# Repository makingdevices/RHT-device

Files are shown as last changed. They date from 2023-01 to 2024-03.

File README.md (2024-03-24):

<!-- Improved compatibility of back to top link: See: https://github.com/othneildrew/Best-README-Template/pull/73 -->

<!--
*** Thanks for checking out the Best-README-Template. If you have a suggestion
*** that would make this better, please fork the repo and create a pull request
*** or simply open an issue with the tag "enhancement".
*** Don't forget to give the project a star!
*** Thanks again! Now go create something AMAZING! :D
-->

<!-- PROJECT SHIELDS -->
<!--
*** I'm using markdown "reference style" links for readability.
*** Reference links are enclosed in brackets [ ] instead of parentheses ( ).
*** See the bottom of this document for the declaration of the reference variables
*** for contributors-url, forks-url, etc. This is an optional, concise syntax you may use.
*** https://www.markdownguide.org/basic-syntax/#reference-style-links
-->
[][ig-url]
[][sponsor-url]
[][stars-url]
[][issues-url]
[][linkedin-url]

<!-- PROJECT LOGO -->
<br />
<div align="center">
  <a href="https://makingdevices.com/links/">
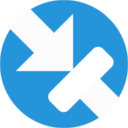
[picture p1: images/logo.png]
    
  </a>

<h3 align="center">Making Devices</h3>

  <p align="center">
    Open Source projects where we struggle with engineering, electronics, coding and who knows what else... In this case, RHT Device is a very simple humidity and temperature sensor, so hopefully you may find it interesting ;)
  </p>
</div>

<!-- TABLE OF CONTENTS -->
<details>
  <summary>Table of Contents</summary>
  <ol>
    <li>
      <a href="#about-the-project">About The Project</a>
      <ul>
        <li><a href="#built-with">Built With</a></li>
      </ul>
    </li>
    <li>
      <a href="#Build-one">Build one</a>
      <ul>
      </ul>
    </li>
    <li><a href="#usage">Usage</a></li>
    <li><a href="#roadmap">Roadmap</a></li>
    <li><a href="#license">License</a></li>
    <li><a href="#contact">Contact</a></li>
    <li><a href="#Sponsor">Sponsor</a></li>
  </ol>
</details>

<!-- ABOUT THE PROJECT -->
## About The Project

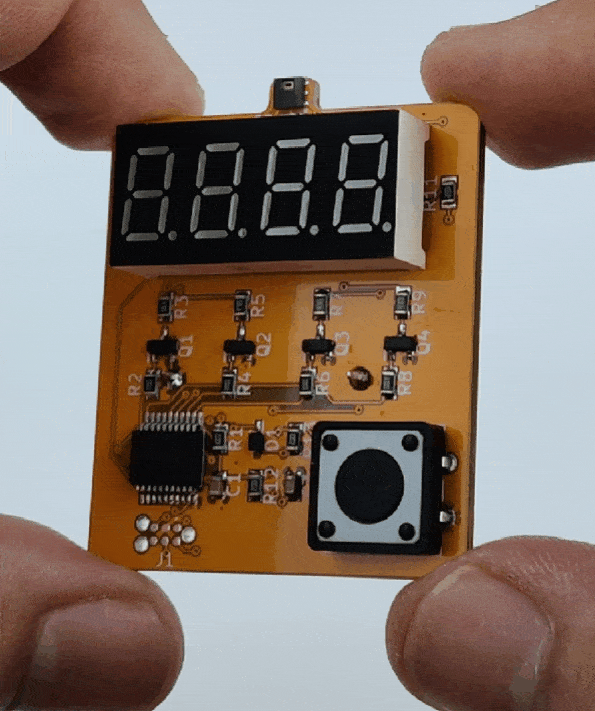
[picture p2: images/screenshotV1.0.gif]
Bytes Counter Shot
[](https://github.com/makingdevices/RHT-device)

RHT Device is a very simple relative humidity and temperature sensor that shows the data in the screen. The project was chosen to test the I2C communication of the PIC18F14k50. 

<p align="right">(<a href="#readme-top">back to top</a>)</p>

### Built With

[][PIC-url]
[][MPLAB-C-url]
[][kicad-url]
[][sponsor-url]

<p align="right">(<a href="#readme-top">back to top</a>)</p>

<!-- GETTING STARTED -->

## Build one
Documentation is being updated.

1. Get the gerber files for the latest version: [V1.0](https://github.com/makingdevices/RHT-device/tree/main/Gerber/Gerber_v1.0.zip) 
2. Send them to a PCB manufacturer ([Our Sponsor is PCBWAY][sponsor-url])
3. You should solder all the components in the board. ([The schematic is available here v1.0][schematic-url])
4. Program the firmware into the pic. ([V1.0 is here][firmware-url])

Enjoy :)

<p align="right">(<a href="#readme-top">back to top</a>)</p>

<!-- USAGE EXAMPLES -->
## Usage

Instructions of use:

- When the button is pressed, the temperature is shown.
- Next time the button is pressed, relative humidity is shown. It will change between temperature and humidity
- After 10s of no use, the screen will be off and the device enters sleep mode.
- One button click will wake up the device for another 10s

<p align="right">(<a href="#readme-top">back to top</a>)</p>

<!-- ROADMAP -->
## Roadmap

- [x] Finish the firmware for the PIC18F14K50
- [x] Validate the RHT-Device board V1.0
- [x] Update all the documentation

See the [open issues](https://github.com/makingdevices/RHT-device/issues) for a full list of proposed features (and known issues).

State: Project <b>FINISHED</b> - 11/05/2023

<p align="right">(<a href="#readme-top">back to top</a>)</p>

<!-- Power Consumption -->
## Power Consumption

One of the main requisites for the board is to obtain a minimum power consumption so the device can live from a coin cell. When the screen is on we obtain:

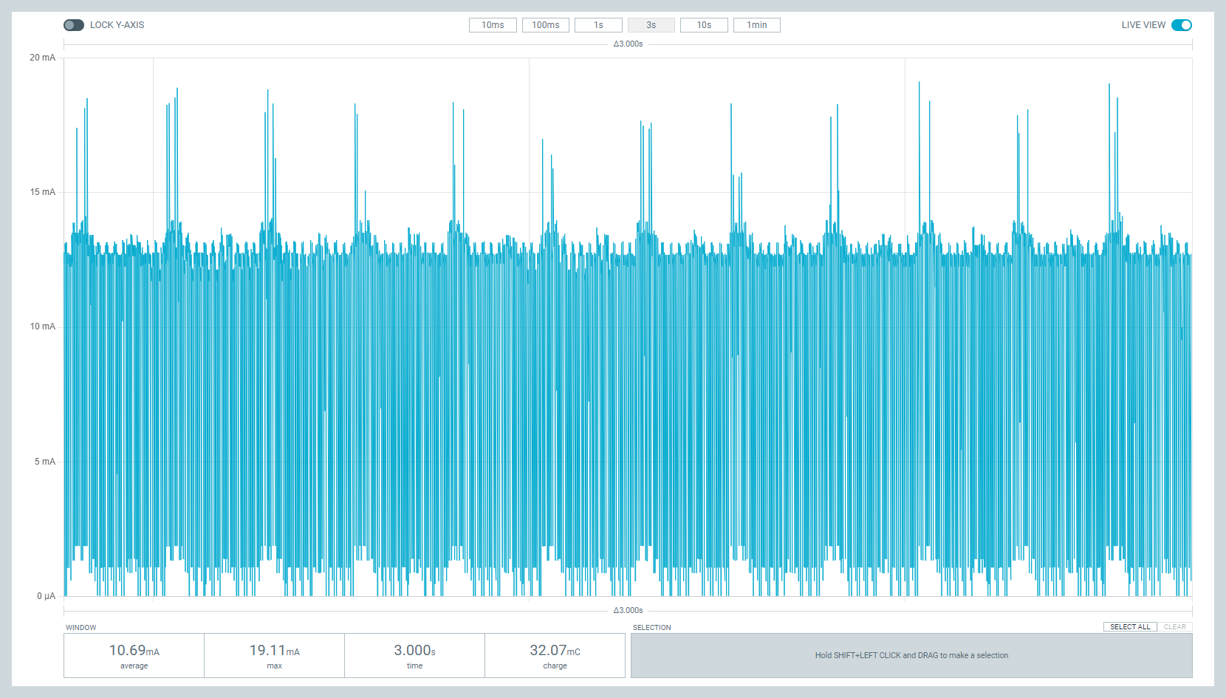
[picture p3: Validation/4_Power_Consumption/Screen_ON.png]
ON Screen consumption Shot
[](https://github.com/makingdevices/RHT-device/tree/main/Validation/)

<b>Average Current</b> = 10.69mA

In sleep mode, the power consumption is as follows:

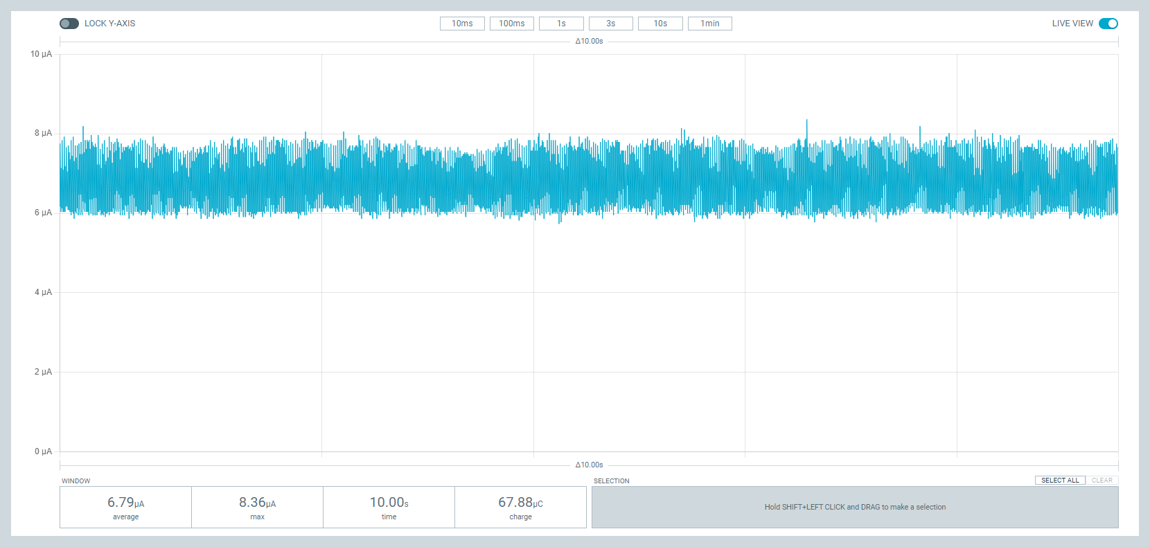
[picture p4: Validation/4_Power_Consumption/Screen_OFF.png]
OFF Screen consumption Shot
[](https://github.com/makingdevices/RHT-device/tree/main/Validation/)

<b>Average Current</b> = 6.79uA

With this data and a normal use of 5 reading a day, the battery should last for several years.

<p align="right">(<a href="#readme-top">back to top</a>)</p>

<!-- LICENSE -->
## License

Distributed under three licenses:
- [Hardware](/License/HW_cern_ohl_s_v2.pdf)
- [Software](/License/SW_GPLv3.0.txt)
- [Documentation](/License/Documentation_CC-BY-SA-4.0.txt)

[GPL v3 License][license-url] 
<p align="right">(<a href="#readme-top">back to top</a>)</p>

<!-- CONTACT -->
## Contact

Making Devices - [@MakingDevices](https://www.instagram.com/makingdevices/)

Project Link: [https://github.com/makingdevices/Thermo-device-logger](https://github.com/makingdevices/RHT-device/)

Other Links: [LinkTree](https://makingdevices.com/links/)

<p align="right">(<a href="#readme-top">back to top</a>)</p>

<!-- Sponsor -->
## Sponsor

[PCBWAY](https://www.pcbway.com/?from=makingdevices) is the most professional PCB manufacturer for prototyping and low-volume production to work with in the world. With more than a decade in the field, They are committed to meeting the needs of their customers from different industries in terms of quality, delivery, cost-effectiveness and any other demanding requests. As Sponsor of Making Devices, they will be in charge of all the PCBs for MDV, allowing both of us to grow together in a long term partnership. We hope you take them into account for your both personal and professional prototypes or products.

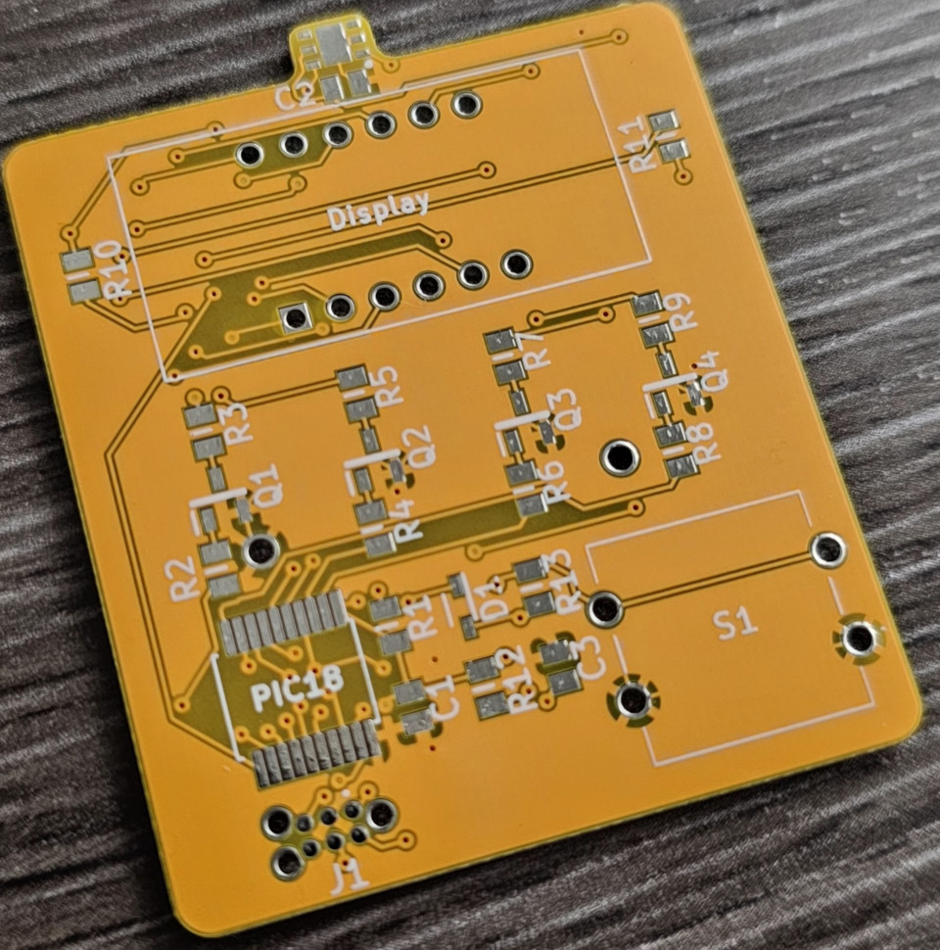
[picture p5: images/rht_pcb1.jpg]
[][sponsor-url]
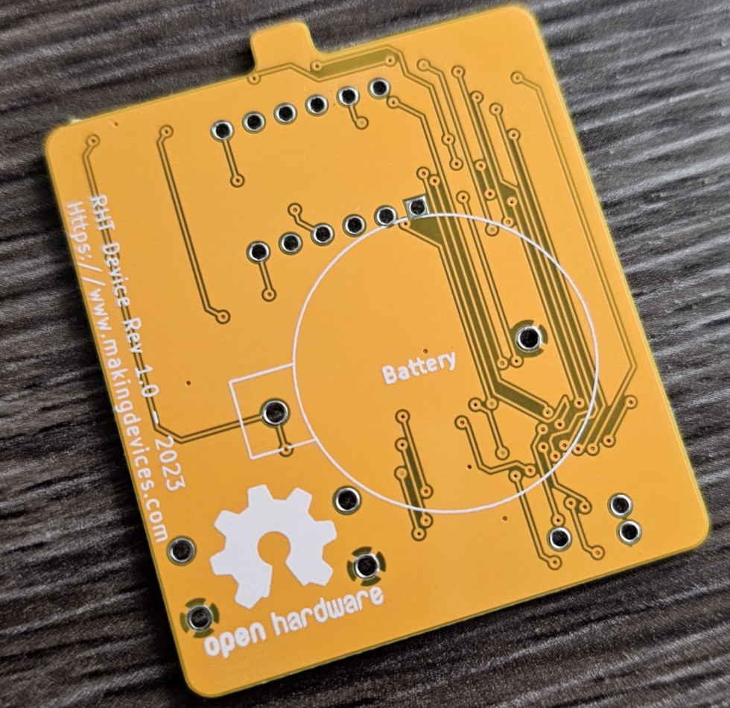
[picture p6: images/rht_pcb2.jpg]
[][sponsor-url]

<p align="right">(<a href="#readme-top">back to top</a>)</p>

<!-- MARKDOWN LINKS & IMAGES -->
<!-- https://www.markdownguide.org/basic-syntax/#reference-style-links -->
[contributors-shield]: https://img.shields.io/github/contributors/makingdevices/RHT-device.svg?style=for-the-badge
[contributors-url]: https://github.com/makingdevices/RHT-device/graphs/contributors
[forks-shield]: https://img.shields.io/github/forks/makingdevices/RHT-device.svg?style=for-the-badge
[forks-url]: https://github.com/makingdevices/RHT-device/network/members
[stars-shield]: https://img.shields.io/github/stars/makingdevices/RHT-device.svg?style=for-the-badge
[stars-url]: https://github.com/makingdevices/RHT-device/stargazers
[issues-shield]: https://img.shields.io/github/issues/makingdevices/RHT-device.svg?style=for-the-badge
[issues-url]: https://github.com/makingdevices/RHT-device/issues
[license-shield]: /images/license.png
[license-url]: https://github.com/makingdevices/RHT-device/tree/main/License
[linkedin-shield]: https://img.shields.io/badge/-LinkedIn-black.svg?style=for-the-badge&logo=linkedin&colorB=555
[linkedin-url]: https://www.linkedin.com/company/making-devices/
[sponsor-shield]: https://img.shields.io/badge/SPONSOR-PCBWAY-black.svg?style=for-the-badge&colorB=1200
[sponsor-url]: https://www.pcbway.com/?from=makingdevices
[sponsor-screenshot-pcb1]: /images/rht_pcb1.jpg
[sponsor-screenshot-pcb2]: /images/rht_pcb2.jpg
[product-screenshot]: images/screenshotV1.0.gif
[pconscreen-screenshot]: /Validation/4_Power_Consumption/Screen_ON.png
[pcoffscreen-screenshot]: /Validation/4_Power_Consumption/Screen_OFF.png
[PIC]: https://img.shields.io/badge/PIC18LF14K50-000000?style=for-the-badge
[PIC-url]: http://ww1.microchip.com/downloads/en/devicedoc/40001350f.pdf
[kicad-shield]: https://img.shields.io/badge/kicad-0b03fc?style=for-the-badge&logo=kicad&logoColor=white
[kicad-url]: https://www.kicad.org/
[YT-screenshot]: images/YT_assembly.PNG
[sponsor-icon]:  https://img.shields.io/badge/-PCBWAY-black.svg?style=for-the-badge&colorB=1200
[ig-shield]: https://img.shields.io/badge/instagram-a83297?style=for-the-badge&logo=instagram&logoColor=white
[ig-url]: https://www.instagram.com/makingdevices/
[MPLAB-C]: https://img.shields.io/badge/MPLAB%20C18-DD0031?style=for-the-badge&logo=C&logoColor=white
[MPLAB-C-url]: https://www.microchip.com/en-us/development-tool/SW006011
[Svelte.dev]: https://img.shields.io/badge/Svelte-4A4A55?style=for-the-badge&logo=svelte&logoColor=FF3E00
[Svelte-url]: https://svelte.dev/
[Laravel.com]: https://img.shields.io/badge/Laravel-FF2D20?style=for-the-badge&logo=laravel&logoColor=white
[Laravel-url]: https://laravel.com
[Bootstrap.com]: https://img.shields.io/badge/Bootstrap-563D7C?style=for-the-badge&logo=bootstrap&logoColor=white
[Bootstrap-url]: https://getbootstrap.com
[JQuery.com]: https://img.shields.io/badge/jQuery-0769AD?style=for-the-badge&logo=jquery&logoColor=white
[JQuery-url]: https://jquery.com 
[schematic-url]: /Output_PDF/Schematic_v1.0.pdf
[firmware-url]: /Firmware/RHT-device.hex

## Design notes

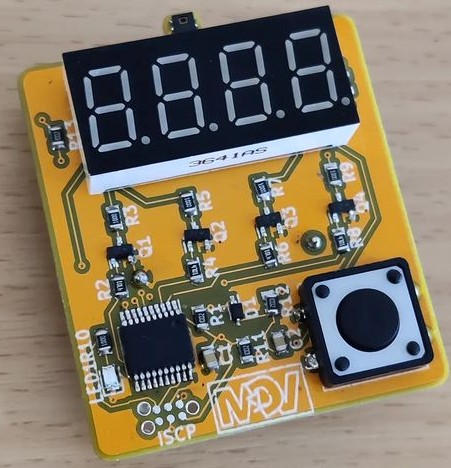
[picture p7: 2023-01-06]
images/screenshot.jpg

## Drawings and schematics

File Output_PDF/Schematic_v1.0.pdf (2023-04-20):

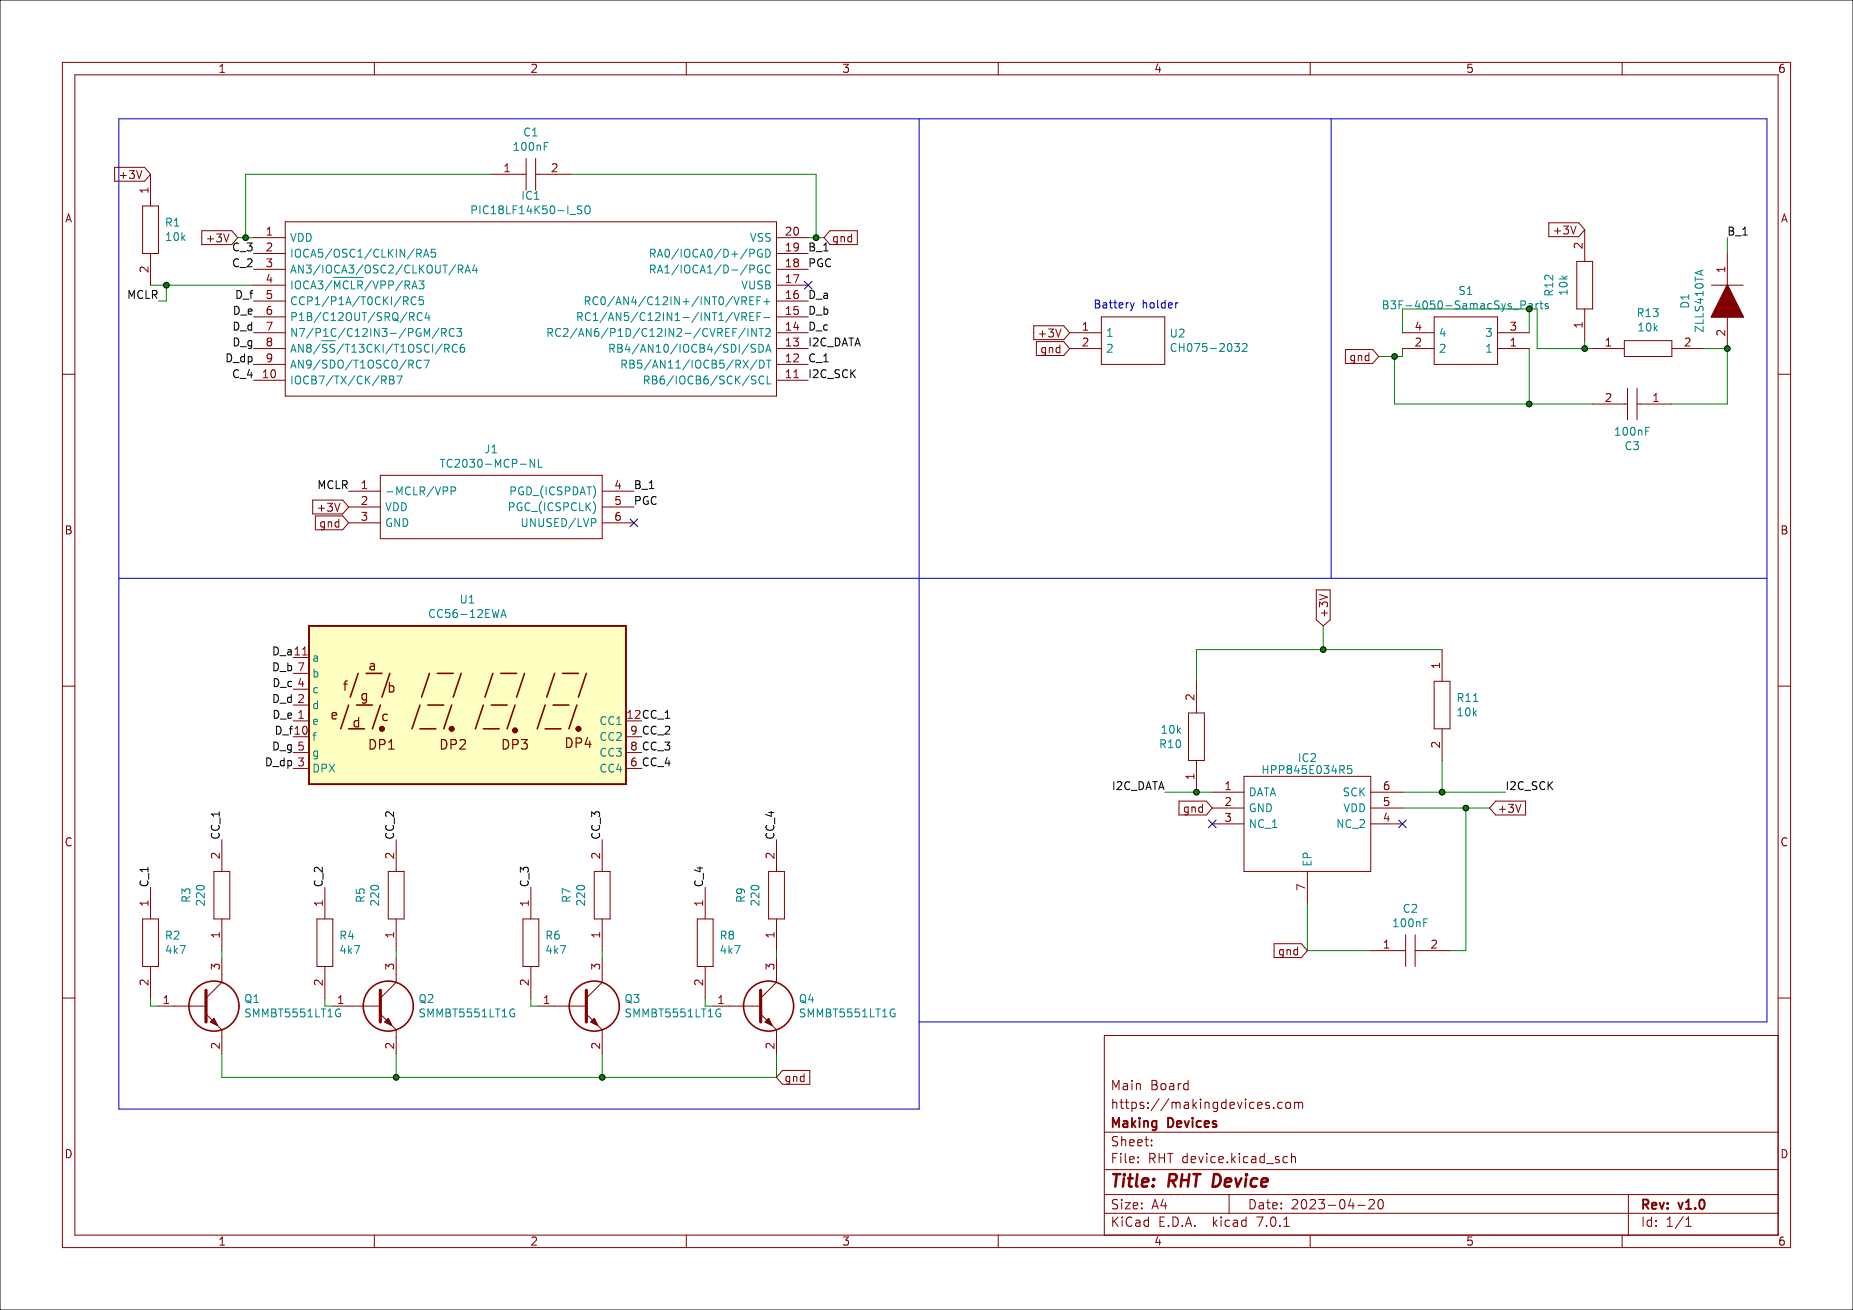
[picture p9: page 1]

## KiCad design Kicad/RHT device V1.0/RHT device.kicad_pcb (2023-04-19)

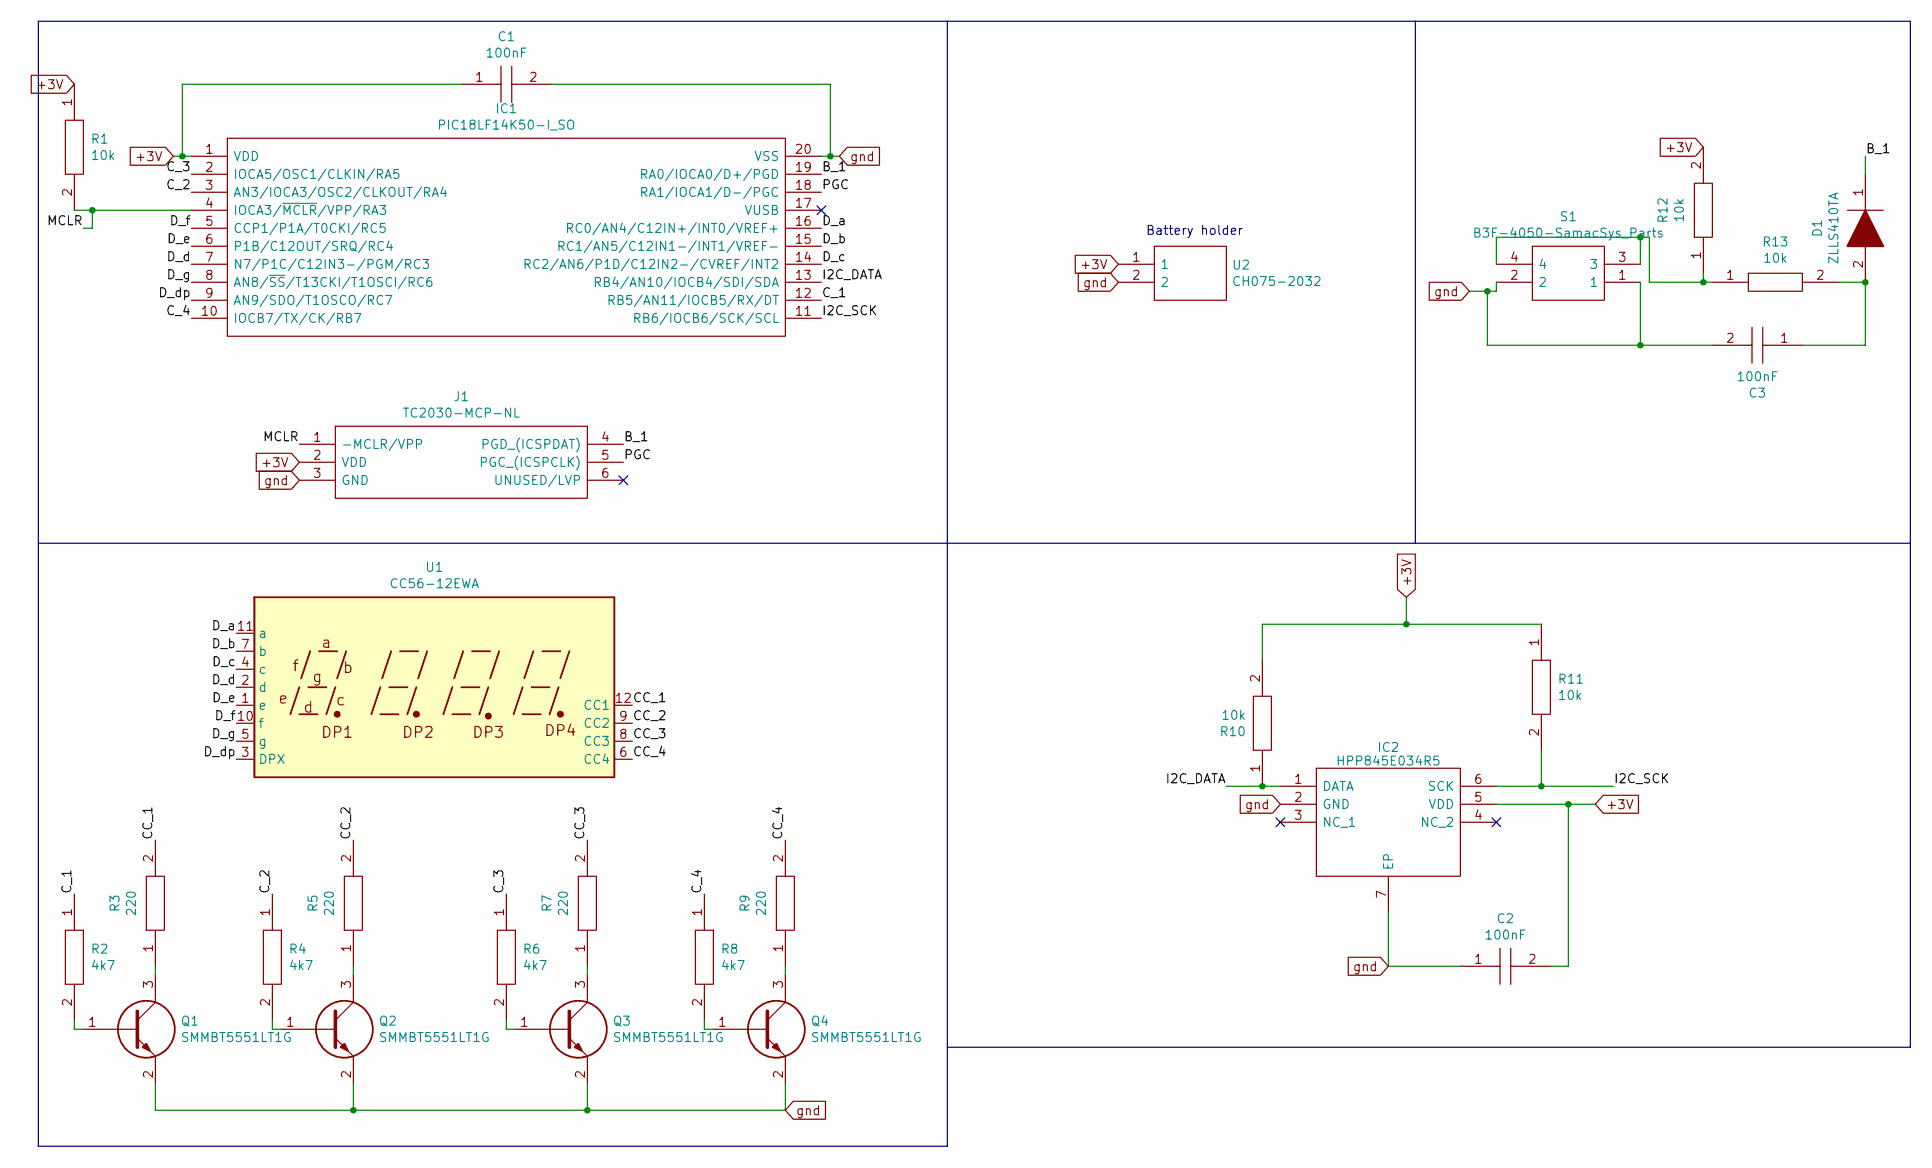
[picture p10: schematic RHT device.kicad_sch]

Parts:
C1, C2, C3: 100nF; CAPC2012X140N; Manufacturer_Part_Number C0805C475M8RACTU
D1: ZLLS410TA; SOD2513X120N; Manufacturer_Part_Number ZLLS410TA
IC1: PIC18LF14K50-I_SO; SSOP-20_5.3x7.2mm_P0.65mm; Manufacturer_Part_Number PIC18LF14K50-I/SO
IC2: HPP845E034R5; SON100P300X300X100-7N; Manufacturer_Part_Number HPP845E034R5; Mouser Part Number 824-HPP845E034R5
J1: TC2030-MCP-NL; Manufacturer_Part_Number TC2030-MCP-NL
Q1, Q2, Q3, Q4: SMMBT5551LT1G; SOT96P237X111-3N; Manufacturer_Part_Number SMMBT5551LT1G
R1, R10, R11, R12, R13: 10k; RESC2012X75N; Manufacturer_Part_Number ERJP6WF1303V
R2, R4, R6, R8: 4k7; RESC2012X75N; Manufacturer_Part_Number ERJP6WF1303V
R3, R5, R7, R9: 220; RESC2012X75N; Manufacturer_Part_Number ERJP6WF1303V
S1: B3F-4050-SamacSys_Parts; B3F4050; Manufacturer_Part_Number B3F-4050; Mouser Part Number 653-B3F-4050
U1: CC56-12EWA; CA56-12EWA
U2: CH075-2032; CH0752032; Manufacturer_Part_Number CH075-2032

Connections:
+3V: C1.1, C2.2, IC1.1 (VDD), IC2.5 (VDD), J1.2 (VDD), R1.1, R10.2, R11.1, R12.2, U2.1
/B_1: D1.1, IC1.19 (RA0/IOCA0/D+/PGD), J1.4 (PGD_(ICSPDAT))
/CC_1: R3.2, U1.12 (CC1)
/CC_2: R5.2, U1.9 (CC2)
/CC_3: R7.2, U1.8 (CC3)
/CC_4: R9.2, U1.6 (CC4)
/C_1: IC1.12 (RB5/AN11/IOCB5/RX/DT), R2.1
/C_2: IC1.3 (AN3/IOCA3/OSC2/CLKOUT/RA4), R4.1
/C_3: IC1.2 (IOCA5/OSC1/CLKIN/RA5), R6.1
/C_4: IC1.10 (IOCB7/TX/CK/RB7), R8.1
/D_a: IC1.16 (RC0/AN4/C12IN+/INT0/VREF+), U1.11 (a)
/D_b: IC1.15 (RC1/AN5/C12IN1-/INT1/VREF-), U1.7 (b)
/D_c: IC1.14 (RC2/AN6/P1D/C12IN2-/CVREF/INT2), U1.4 (c)
/D_d: IC1.7 (N7/P1C/C12IN3-/PGM/RC3), U1.2 (d)
/D_dp: IC1.9 (AN9/SDO/T1OSCO/RC7), U1.3 (DPX)
/D_e: IC1.6 (P1B/C12OUT/SRQ/RC4), U1.1 (e)
/D_f: IC1.5 (CCP1/P1A/T0CKI/RC5), U1.10 (f)
/D_g: IC1.8 (AN8/~SS/T13CKI/T1OSCI/RC6), U1.5 (g)
/I2C_DATA: IC1.13 (RB4/AN10/IOCB4/SDI/SDA), IC2.1 (DATA), R10.1
/I2C_SCK: IC1.11 (RB6/IOCB6/SCK/SCL), IC2.6 (SCK), R11.2
/MCLR: IC1.4 (IOCA3/~MCLR/VPP/RA3), J1.1 (-MCLR/VPP), R1.2
/PGC: IC1.18 (RA1/IOCA1/D-/PGC), J1.5 (PGC_(ICSPCLK))
unnamed: C3.1, D1.2, R13.2
unnamed: Q1.1, R2.2
unnamed: Q1.3, R3.1
unnamed: Q2.1, R4.2
unnamed: Q2.3, R5.1
unnamed: Q3.1, R6.2
unnamed: Q3.3, R7.1
unnamed: Q4.1, R8.2
unnamed: Q4.3, R9.1
unnamed: R12.1, R13.1, S1.3, S1.4
gnd: C1.2, C2.1, C3.2, IC1.20 (VSS), IC2.2 (GND), IC2.7 (EP), J1.3 (GND), Q1.2, Q2.2, Q3.2, Q4.2, S1.1, S1.2, U2.2

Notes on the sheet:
Battery holder

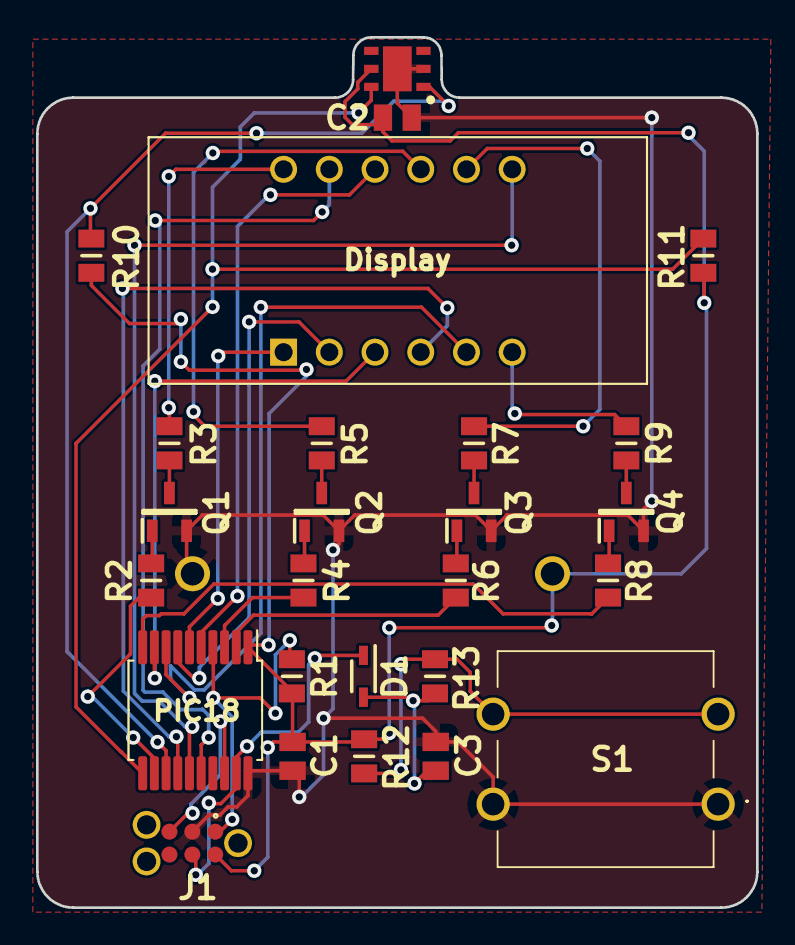
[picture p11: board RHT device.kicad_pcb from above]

Board: 2 copper layers, 40.0 x 48.4 mm, 27 parts (1 on the bottom side), 33 nets.

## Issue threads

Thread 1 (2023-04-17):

[Requisite][v1.0] Readings

makingdevices, 2023-04-17:
The board should provide the following readings:

- [x] Temperature in the range of -20 to 100ºC with +-1ºC accuracy
- [x] Relative humidy from 0 to 99% with +-2% accuracy. There should be a compensation for temperature.

As the sensor is intended for another type of use (not a handheld measurement device) some errors or malfunctioning is tolerated, as this is a proof of test for the sensor.

makingdevices, 2023-05-11:
Readings from the I2C sensor are done. There is a compensation humidity for temperature, as it was explained by the supplier

Closed 2023-05-11.

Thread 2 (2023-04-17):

[Requisite][v1.0] Low battery

makingdevices, 2023-04-17:
The display must warn when the battery is low (<2.25V). For this purpose, the feature from the sensor will be used.

- [ ] The display must show "batt" text for a few seconds when the battery is low voltage

Closed 2023-05-11.

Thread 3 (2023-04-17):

[Requisite][V1.0] Button

makingdevices, 2023-04-17:
The button will be used to switch between temperature and humidity reading as well as waking up from deep sleep.

- [x] The button switch between temperature and humidity reading when the device is up.
- [x] The button wake up the device when the board is in deep sleep.
- [x] No bouncing effect in the button.

Closed 2023-05-11.

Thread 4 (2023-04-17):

[Requisite][V1.0] Deep Sleep and power consumption

makingdevices, 2023-04-17:
The battery of the device should work for at least 1 year of normal use*.

- [x] The device turns off the display after 10s of use.
- [x] Deep Sleep consumption is lower than 0.1 mA.
- [x] The power consumption during measurement should be as low as possible (Expected: <10mA).

Normal use*: 5 Reading of temperature and humidity each day.

makingdevices, 2023-05-11:
Proof can be seen in the Validation Folder.

ON screen consumption: 10.69mA
OFF screen consumption: 6.79uA

Closed 2023-05-11.

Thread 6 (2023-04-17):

[HW][v1.0] Reduce the cost

makingdevices, 2023-04-17:
For the new version of the board, the cost will be reduced.

- [x] Eliminate LED and resistor from the board
- [x] New board must be 2-layer instead of 4-layered PCB

makingdevices, 2023-05-11:
Reduced costs with fewer components and a simpler pcb board. HW V1.0 assembled

Closed 2023-05-11.

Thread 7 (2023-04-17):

[HW][v1.0] New footprint for HTU20D

makingdevices, 2023-04-17:
In order to improve solderability, a new footprint for the HTU20D is needed in the board.

- [x] Improve HTU20D footprint.

makingdevices, 2023-05-11:
Done in HW V1.0. Assembled and tested

Closed 2023-05-11.

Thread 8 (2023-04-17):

[BUG] Button is creating a shortcircuit

makingdevices, 2023-04-17:
The button footprint is wrong, so only two of the four legs can be connected at the same time to avoid any problem.

- [x] Fix button tracks in the new PCB.

makingdevices, 2023-05-11:
PCB was redesign. V1.0 fix the bug

Closed 2023-05-11.

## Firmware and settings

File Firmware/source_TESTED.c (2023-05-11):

/*	Making Devices 2022
	https://makingdevices.com
	Rubén García Segovia
	RHT Device
*/
#define I2C_IO_V5

#include <p18f14k50.h>
#include <delays.h>
#include <i2c.h>

 // setup config bits 
 #pragma config PCLKEN=OFF
 #pragma config FOSC = IRC
 #pragma config BOREN = OFF 
 #pragma config WDTEN = OFF 
 #pragma config LVP = OFF  

/** Default I2C address for the HTU21D. */
#define HTU31D_DEFAULT_I2CADDR (0x40)

/** Read temperature and humidity. */
#define HTU31D_READTEMPHUM (0x00)

/** Start a conversion! */
#define HTU31D_CONVERSION (0x40)

/** Read serial number command. */
#define HTU31D_READSERIAL (0x0A)

/** Enable heater */
#define HTU31D_HEATERON (0x04)

/** Disable heater */
#define HTU31D_HEATEROFF (0x02)

/** Reset command. */
#define HTU31D_RESET (0x1E)

char digit = 0;
char const vector[] = {0b00111111,0b00000110,0b01011011,0b01001111,0b01100110,0b01101101,0b01111101,0b00000111,0b01111111,0b01100111,0b001000000,0b01111001}; //Numbers 8-segment codification
char const letters[] = {0b01011110,0b01110100};
char const batmess[] = {0b01111000,0b01111000,0b01110111,0b01111100};
char number[] = {0,0,0,0}; //Number Storage
char dot = 5;
char buzz = 0; //Buzzer counter
char data[] = {0,0,0,0,0,0}; //Dato
float temperature = 0;
float humidity = 0;
float rhcompensation = 0;
int temp = 0;
int reset = 0; //Reset event counter
int deep_sleep = 0; //Deep Sleep counter
int buzz_reset = 0;  //Enable-disable buzz event counter
char buzz_en = 1; //Buzzer enable
int sleep_time = 2000; //Time before deep sleep
int time_letters = 500; //time for type of measurement message
int batt_time = 300; //Time for battery message
int event_timer = 500; //The time we need to mantain pressed the botons to execute reset/sound events.
int bouncing_timer_var = 25; //The time we need to wait between two button actions
int bouncing_time = 0;
char state = 0;  // 0 = temperature, 1 = humidity
char command = 0;
char battery = 0;

void InitOSC(void); 
void _low_isr (void);
void _high_isr (void);
void Interrupts_enable (void);

#pragma code low_vector=0x18 //Low interrupt priority starts at 0x18
void low_interrupt(void)
{
_asm goto _low_isr _endasm
}

#pragma code high_vector=0x08 //High interrupt priority starts at 0x08
void high_interrupt(void)
{
_asm goto _high_isr _endasm
}
#pragma code


#pragma interrupt _low_isr

void _low_isr (void){

}

#pragma interrupt _high_isr
void _high_isr (void)   //High priority interrupt.
{
char i=0; 

if(INTCONbits.TMR0IF) //Timer0 interrupt
	{

		//We set the timer0 again
		TMR0H = 0xFE;
		TMR0L = 0xC7;
	
		LATC = 0; //Turn off the display before changing the number AND RESET
		LATA = 0;
		switch(digit){  //Print the numbers over the display
			case 3:		//we light the correct display
				LATB = 0b10001111; 
				digit = 0;
				break;
			case 0:
				LATB = 0b00001111;
				LATA = 0b00100000; 
				digit = 1;
				break;
			case 1:
				LATB = 0b00001111; 
				LATA = 0b00010000; 
				digit = 2;
				break;
			case 2:
				LATB = 0b00101111; 
				digit = 3;
				break;
			default:
				break;
		}
		if((battery>0) && (deep_sleep < batt_time)){
			LATC = batmess[digit];
		} else {
			if(digit>0){
				if(digit==dot)LATC = vector[number[digit]] + 0b10000000;
				else LATC = vector[number[digit]];  //we write the correct number depending on the display.
			} else {
				if(deep_sleep<time_letters)LATC = letters[state];
				else{
					if(digit==dot)LATC = vector[number[digit]] + 0b10000000;
					else LATC = vector[number[digit]];  //we write the correct number depending on the display.
				}
			}
		}
	}	
	INTCONbits.TMR0IF = 0; // reset overflow bit (for timer0).

 bouncing_time++;
 if(INTCONbits.RABIF) //if we are pressing a button...
      { 
		OSCCONbits.IDLEN = 1; //Set idle mode. 

		if(PORTAbits.RA0 == 0 && deep_sleep <= sleep_time && bouncing_time >= bouncing_timer_var){ //
			bouncing_time = 0;
			if(state==0)state = 1;
			else state = 0;
		}	

		deep_sleep = 0; //We restart the deep sleep counter
      	INTCONbits.RABIF = 0;	//Clear RAB Interrupt Flag 
      }

	deep_sleep++;  //We increase time before sleep
	if (deep_sleep >= sleep_time){ //If the time for sleep has come
		LATA = 0; //turn off the display
		LATB = 0;
		LATC = 0;
		OSCCONbits.IDLEN = 0; //Prepare the microchip for deep sleep.
	}
}

/*****************Float to display*************************/
// Mode == 1 Temperature // Mode == 2 Humidity

void floattodisplay(char mode)
{
	int i,j;
	if (mode == 1){
		if((temperature<100 && temperature>=0)||(temperature>-10 && temperature<0)){
			i = (int)((float)temperature*100);
			dot = 2;
		}
		else{
			i = (int)((float)temperature*10);
			dot = 1;
		}
		if(temperature<0)i = -i;
		number[0] = i % 10;
		i /= 10;
		number[1] = i % 10;
		i /= 10;
		number[2] = i % 10;
		i /= 10;
		if(temperature<0){
			number[3] = 10;
		} else number[3] = i % 10;
	} else {
		if((humidity>10)){
			i = (int)((float)humidity*100);
			dot = 2;
		}
		else{
			i = (int)((float)humidity*10);
			dot = 1;
		}
		number[0] = i % 10;
		i /= 10;
		number[1] = i % 10;
		i /= 10;
		number[2] = i % 10;
		i /= 10;
		number[3] = i % 10;
	}
	for(j==0;j<4;j++){
		if(number[j]>10 || number[j]<0)number[j] = 11;
	}
}
/* ****************** Obtain data from I2C ****************** */

void getdata(char reading){
		if(reading==1) command = 0xF3;
		if(reading==2) command = 0xF5;
		StartI2C();                        // Send START condition
		WriteI2C(0b10000000);  // Send address with R/W cleared for write 0x40
		WriteI2C(command);       // Conversion command NO HOLD          
		Delay10TCYx(200);
		StartI2C();   
		WriteI2C(0b10000001);  // Send address with R/W set for read 0x41
		data[0] = ReadI2C();               // Read first byte of data
		AckI2C(); 
		data[1] = ReadI2C();
		AckI2C(); 
		data[2] = ReadI2C();
		NotAckI2C();                       // Send NACK
		StopI2C();
		if(reading==1){            
			temp = data[0];
			temp = temp<<8;
			temp = temp+data[1];
			temperature = temp;
			temperature = temperature/65536;
			temperature = temperature*175.72;
			temperature = temperature - 46.85;
		}
		if(reading==2){
			temp = data[0];
			temp = temp<<8;
			temp = temp+data[1];
			humidity = temp;
			humidity = humidity/65536;
			humidity = humidity*125.0;
			humidity = humidity - 6;
			rhcompensation = (-0.15)*(25.0-temperature);
			humidity = humidity + rhcompensation;
		} 
		temp = 0;
}

void batterylevel(void){
	StartI2C();  
	WriteI2C(0b10000000);  // Send address with R/W cleared for write 0x40
	WriteI2C(0xE7);  // READ REGISTER FOR BATTERY LEVEL   
	Delay10TCYx(100);
	StartI2C();
	WriteI2C(0b10000001);  // Send address with R/W cleared for write 0x41  
	battery = ReadI2C()&0b01000000;     // Read first byte of data
	NotAckI2C();                       // Send NACK
	StopI2C();
}

void resolutionhigh(void){
	StartI2C();  
	WriteI2C(0b10000000);  // Send address with R/W cleared for write 0x40
	WriteI2C(0xE7);  // READ REGISTER 
	Delay10TCYx(100);
	StartI2C();
	WriteI2C(0b10000001);  // Send address with R/W cleared for write 0x41  
	temperature = ReadI2C();               // Read first byte of data
	NotAckI2C();                       // Send NACK
	StartI2C();
	WriteI2C(0b10000000);  // Send address with R/W cleared for write 0x41  
	WriteI2C(0xE6);  // WRITE REGISTER 
	WriteI2C(0b00000010); //12 bits RH // 14 bits TEMP
	StopI2C();
}

/* ****************** MAIN ****************** */
char init = 0;
void main(void)
{
	ANSELHbits.ANS10 = 0;	  // Desactivate ANALOG pins

	if(init == 0){
		InitOSC();     //Internal OSC 16MHz 
		Delay10TCYx(1000);
    	Interrupts_enable(); //Enable RA0 & RA1 interrupts
		TRISB =0; //Set port B as output
		TRISC =0; //Set port C as output
		TRISBbits.TRISB4 = 1;     // SDIO -> RB4      
    	TRISBbits.TRISB6 = 1;     // SCLK -> RB6
		init = 1; //We only run this loop once.
		OSCCONbits.IDLEN = 1; //We activate idle mode.

		OpenI2C(MASTER_FIRMW, SLEW_OFF);   //I2C Communication
		SSPADD = 0x77; 
		resolutionhigh();
	}
	getdata(state+1);
	Delay10TCYx(200);
	batterylevel();
	floattodisplay(state+1);
	Sleep(); //Sleep either idle or deep mode!
	//Delay10TCYx(120);  
}

 void InitOSC(void) 
 {    
      OSCCON  = 0b10010110;   //Internal 250KHz    31KHz?? OSCCON  = 0b10010110;
 } 

 void Interrupts_enable(void) 
 {    
	TRISA = 0b11001111; //A port as input
	PORTA = 0;
    //INTCON2bits.RABPU = 0; // Enable Pull-UP on port A-B
    INTCON2bits.RABIP = 1; // Change on port = High priority
	IOCA  = 0b00000011;        //Enable Interrupt on Change for Pin 4 of Port A 
    INTCONbits.RABIE = 1;      //Enable RA and RB Port Change Interrupt 

	T0CONbits.T08BIT = 0;	//5ms at 250Khz timer 0 interrupt
	T0CONbits.T0CS = 0;
	T0CONbits.PSA = 1;
	TMR0H = 0xFE;
	TMR0L = 0xC7;
	T0CONbits.TMR0ON = 1;

	RCONbits.IPEN       = 1;    //Enable Interrupt Priorities
    INTCONbits.GIEL     = 1;    //Enable Low Priority Interrupt
    INTCONbits.GIEH     = 1;    //Enable high priority interrupts        
    INTCONbits.TMR0IE   = 1;    //Enable Timer0 Interrupt
	INTCONbits.T0IE     = 1;   
    INTCON2bits.TMR0IP  = 1;    //TMR0 set to low Priority Interrupt
    INTCONbits.TMR0IF = 0;  // T0 int flag bit cleared before starting
    T0CONbits.TMR0ON = 1;   // timer0 START
	INTCONbits.GIE = 1; 		   //Enable all unmasked interrupts   
 } 
 
 

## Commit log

2023-01-06 Update files
    [RHT device-B_Cu.gbr, RHT device-B_Mask.gbr, RHT device-B_Paste.gbr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]
2023-04-19 New HW version 1.0
    [RHT device.kicad_pcb, RHT device.kicad_sch]
2023-05-11 V1.0 files
    [RHT device.kicad_pcb, RHT device.kicad_sch, RHT device.sch]
2023-05-16 Power consumption
